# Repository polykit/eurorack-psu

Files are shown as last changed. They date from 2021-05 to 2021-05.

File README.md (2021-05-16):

# Eurorack Power Supply

This repository contains KiCad schematics and PCB layout for an Eurorack power supply. It delivers +12V, -12V and +5V. A 12V AC/AC 1A to 2A wall wart power supply is needed. Gerber files can be found [here](plots/)

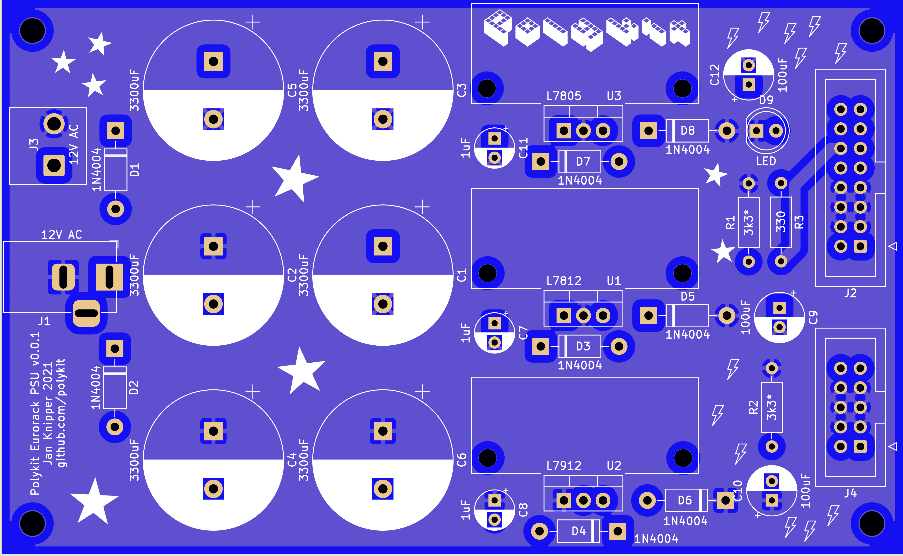
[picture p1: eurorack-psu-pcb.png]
Eurorack Power Supply PCB


## BOM

|Reference |Quantity|Value |
|---|---|---|
|C1 C2 C3 C4 C5 C6 |6 |3300uF |
|C9 C10 C12 |3 |100uF |
|C7 C8 C11 |3 |1uF |
|D1 D2 D3 D4 D5 D6 D7 D8 |8 |1N4004 |
|D9 |1 |LED 5mm |
|J1 |1 |Barrel Jack Socket 5.5mm/2.1mm |
|J2 |1 |IDC 16-pin |
|J3 |1 |2-pin 5.4mm** |
|J4 |1 |IDC 10-pin |
|R1 R2 |2 |3k3* |
|R3 |1 |330 |
|U1 |1 |L7812 |
|U2 |1 |L7912 |
|U3 |1 |L7805 |
|Heatsink |3 |for TO-220 (max. size 30mm x 13mm) eg. SK 145/37,5|

\* load resistors can be omitted

\** alternative connector to barrel jack

## References

http://musicfromouterspace.com/analogsynth_new/WALLWARTSUPPLY/WALLWARTSUPPLY.php

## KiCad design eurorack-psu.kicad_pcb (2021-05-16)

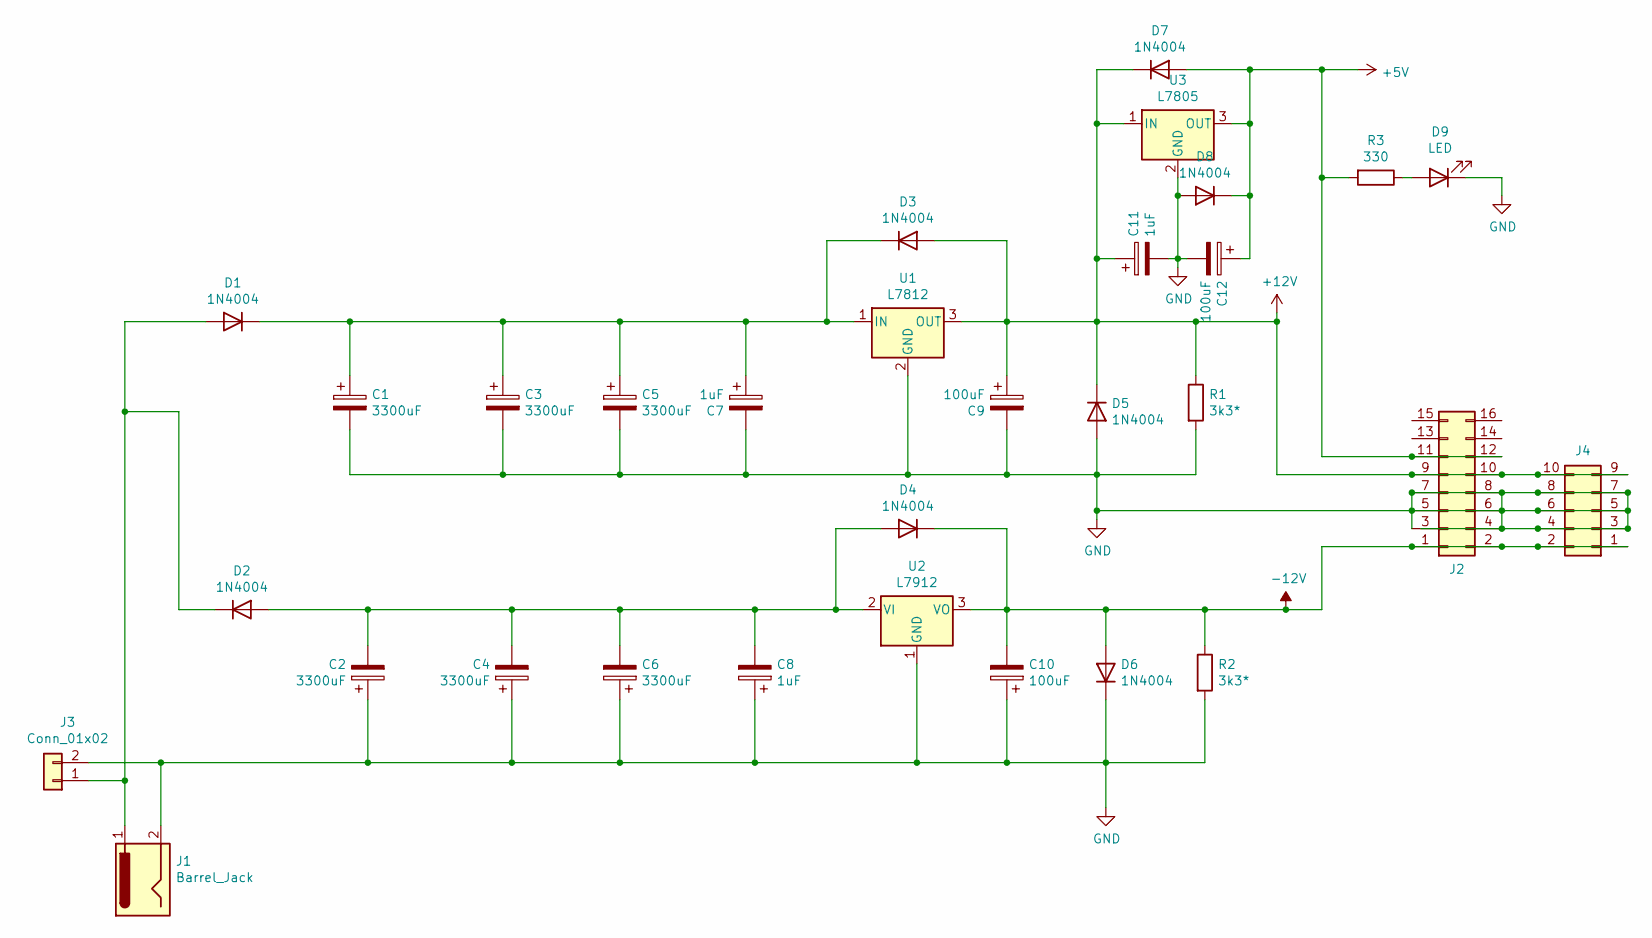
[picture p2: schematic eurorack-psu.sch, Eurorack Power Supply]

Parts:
C1, C2, C3, C4, C5, C6: 3300uF; CP_Radial_D18.0mm_P7.50mm
C7, C8, C11: 1uF; CP_Radial_D5.0mm_P2.50mm
C9, C10, C12: 100uF; CP_Radial_D6.3mm_P2.50mm
D1, D2, D3, D4, D5, D6, D7, D8: 1N4004; D_DO-41_SOD81_P10.16mm_Horizontal
D9: LED; LED_D5.0mm
J1: Barrel_Jack; BarrelJack_Horizontal
J2: Connector_Generic:Conn_02x08_Odd_Even; IDC-Header_2x08_P2.54mm_Vertical
J3: Conn_01x02; SolderWire-1sqmm_1x02_P5.4mm_D1.4mm_OD2.7mm
J4: Conn_02x05_Odd_Even; IDC-Header_2x05_P2.54mm_Vertical
R1, R2: 3k3*; R_Axial_DIN0207_L6.3mm_D2.5mm_P10.16mm_Horizontal
R3: 330; R_Axial_DIN0207_L6.3mm_D2.5mm_P10.16mm_Horizontal
U1: L7812; TO-220-3_Vertical
U2: L7912; TO-220-3_Vertical
U3: L7805; TO-220-3_Vertical

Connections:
+5V: C12.1, D7.2 (A), D8.1 (K), J2.11, J2.12, R3.2, U3.3 (OUT)
+12V: C9.1, C11.1, D3.2 (A), D5.1 (K), D7.1 (K), J2.9, J2.10, J4.9, J4.10, R1.1, U1.3 (OUT), U3.1 (IN)
-12V: C10.2, D4.1 (K), D6.2 (A), J2.1, J2.2, J4.1, J4.2, R2.1, U2.3 (VO)
GND: C1.2, C2.1, C3.2, C4.1, C5.2, C6.1, C7.2, C8.1, C9.2, C10.1, C11.2, C12.2, D5.2 (A), D6.1 (K), D8.2 (A), D9.1 (K), J1.2, J2.3, J2.4, J2.5, J2.6, J2.7, J2.8, J3.2, J4.3, J4.4, J4.5, J4.6, J4.7, J4.8, R1.2, R2.2, U1.2 (GND), U2.1 (GND), U3.2 (GND)
unnamed: C1.1, C3.1, C5.1, C7.1, D1.1 (K), D3.1 (K), U1.1 (IN)
unnamed: C2.2, C4.2, C6.2, C8.2, D2.2 (A), D4.2 (A), U2.2 (VI)
unnamed: D1.2 (A), D2.1 (K), J1.1, J3.1
unnamed: D9.2 (A), R3.1

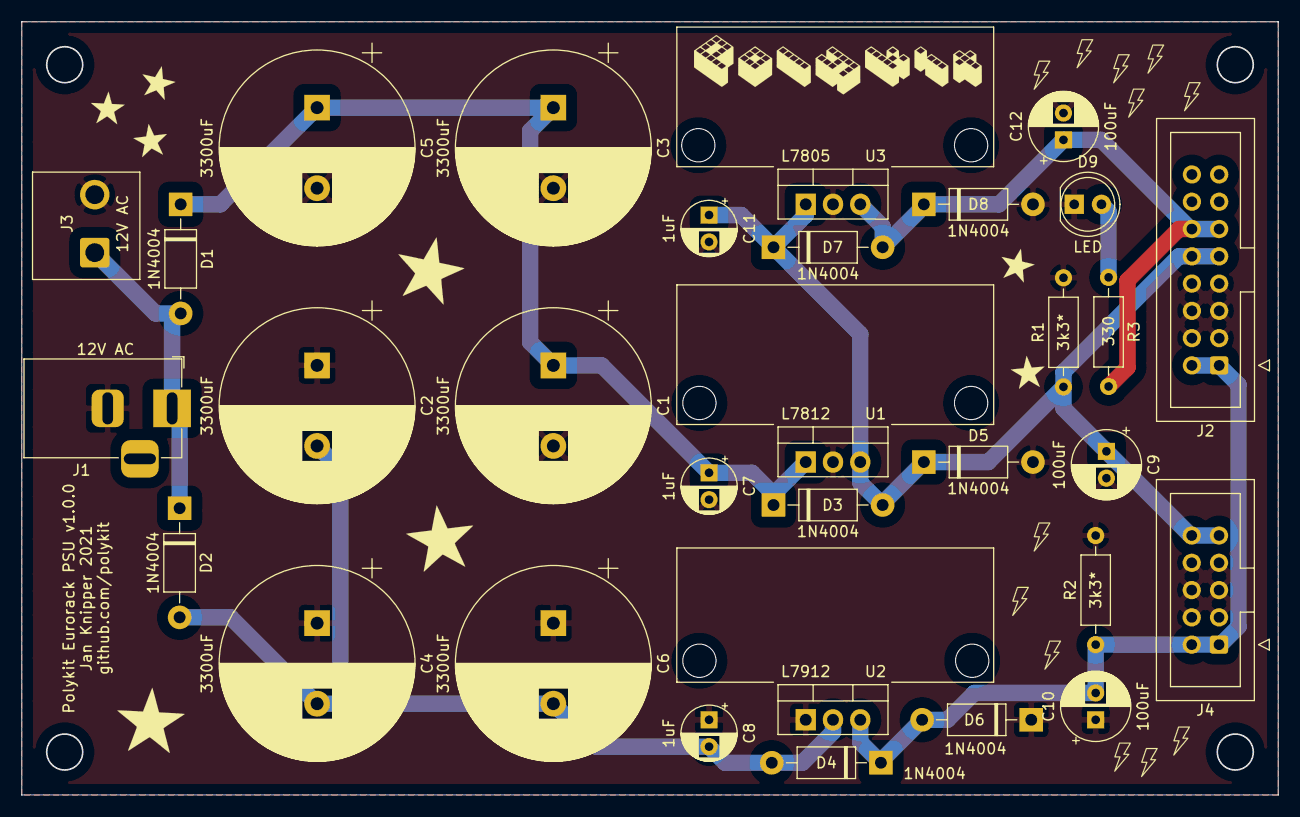
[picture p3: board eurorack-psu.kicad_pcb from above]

Board: 2 copper layers, 117.0 x 72.0 mm, 31 parts (0 on the bottom side), 8 nets.

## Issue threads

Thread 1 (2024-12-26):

Power issues

8lall0, 2024-12-26:
Hi,
i built this very psu, and i'm noticing that it tends to turn on and off (as for the LED).

I'm using a 12v ac (11.5 virtual voltage), may it be the problem?

Thanks!

polykit, 2024-12-27:
Hi @8lall0
sounds like the voltage regulators are under powered or there is a short circuit/you are drawing too much current from the PSU. Check if the input is 12V AC and that there's no short between the output voltages and/or ground. There should be around +17V at the input of the 7812 and ground, and -17V between the input of the 7912 and ground.
I hope this helps. Cheers!

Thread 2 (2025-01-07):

-12V issue

Jaepke, 2025-01-07:
Ive built this Power suppy, +12 an +5 seem to work perfectly but i only get -10V at the 7912.
Any idea how to solve this issue?

Jaepke, 2025-01-07:
Ive now measured from the jacks input ground and now the multimeter show -12 so I assume there is an issue with the ground somewhere?

Jaepke, 2025-01-07:
Okay seems as i am wrong ive measured wrong way around :(
